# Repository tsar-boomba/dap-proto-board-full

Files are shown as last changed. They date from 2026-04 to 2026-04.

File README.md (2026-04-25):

# Bomb DAP Full Proto Board

The culmination of all of my learning during the Spring '26 semester. All the way from making a simple dev board for the TAD5212 DAC, to making a RP2350 board, and now this. Everything combined on one 6-layer board.

# V1 Pinouts

- GPIO0 -> PSRAM_CS
- GPIO1 -> npm1300 GPIO0
- GPIO2 -> DISP_IO_ON (level-shifter enable)
- GPIO3 -> Display Backlight
- GPIO4 -> Display SCLK
- GPIO5 -> Display MOSI
- GPIO6 -> Display MISO
- GPIO7 -> Display DC & SDA
- GPIO8 -> Display CS & SCL
- GPIO(9-11) -> Broken out
- GPIO12 -> SD MISO
- GPIO13 -> SD CS
- GPIO14 -> SD SCLK
- GPIO15 -> SD MOSI
- GPIO16 -> npm1300 SDA
- GPIO17 -> npm1300 SCL
- GPIO18 -> SD ON (load switch & level-shifter enable)
- GPIO19 -> TAD GPIO1
- GPIO20 -> TAD SDA
- GPIO21 -> TAD SCL
- GPIO(22-26) -> Broken out
- GPIO27 -> TAD DIN
- GPIO28 -> TAD FSYNC
- GPIO29 -> TAD BCLK

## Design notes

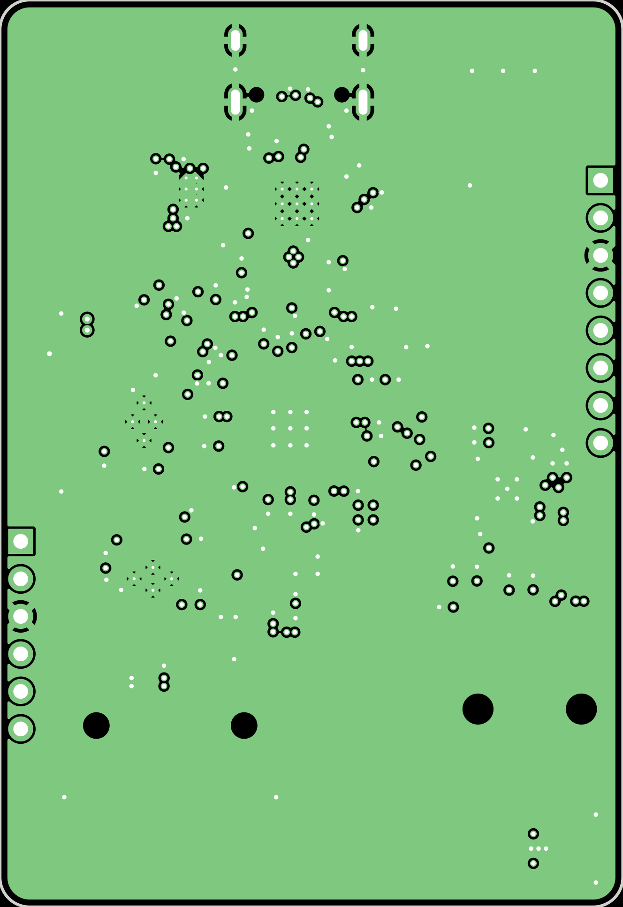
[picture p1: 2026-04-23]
In1.Cu.png

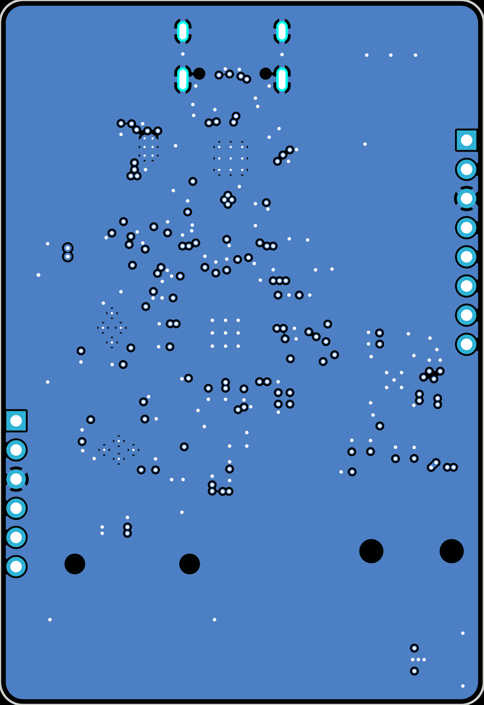
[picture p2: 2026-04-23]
B.png

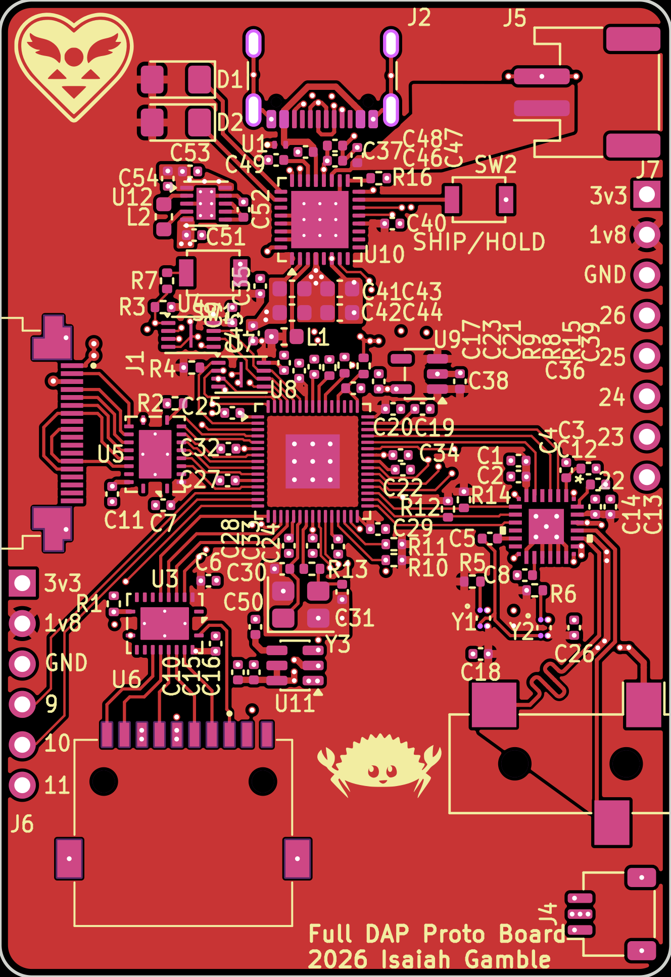
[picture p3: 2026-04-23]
F.png

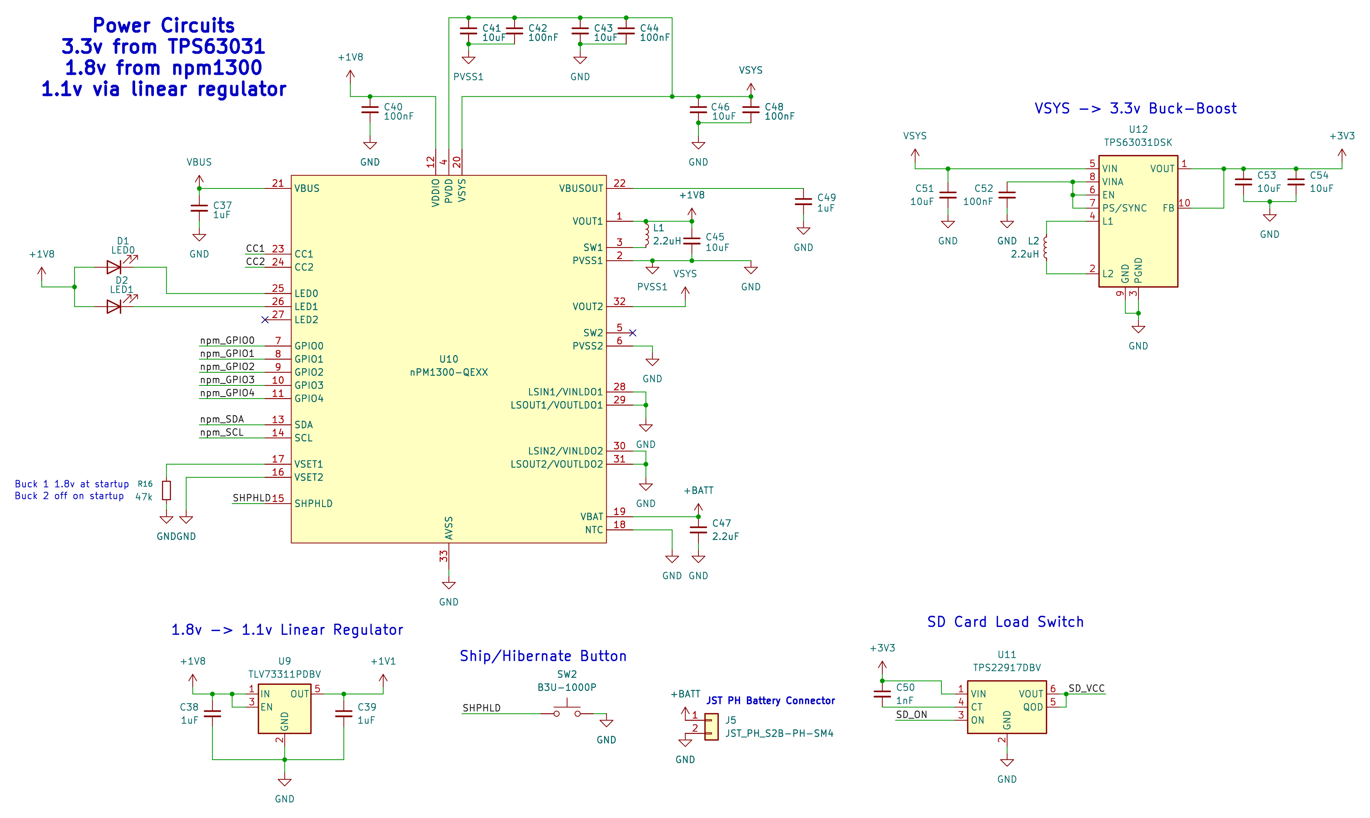
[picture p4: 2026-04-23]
SCH_2.png

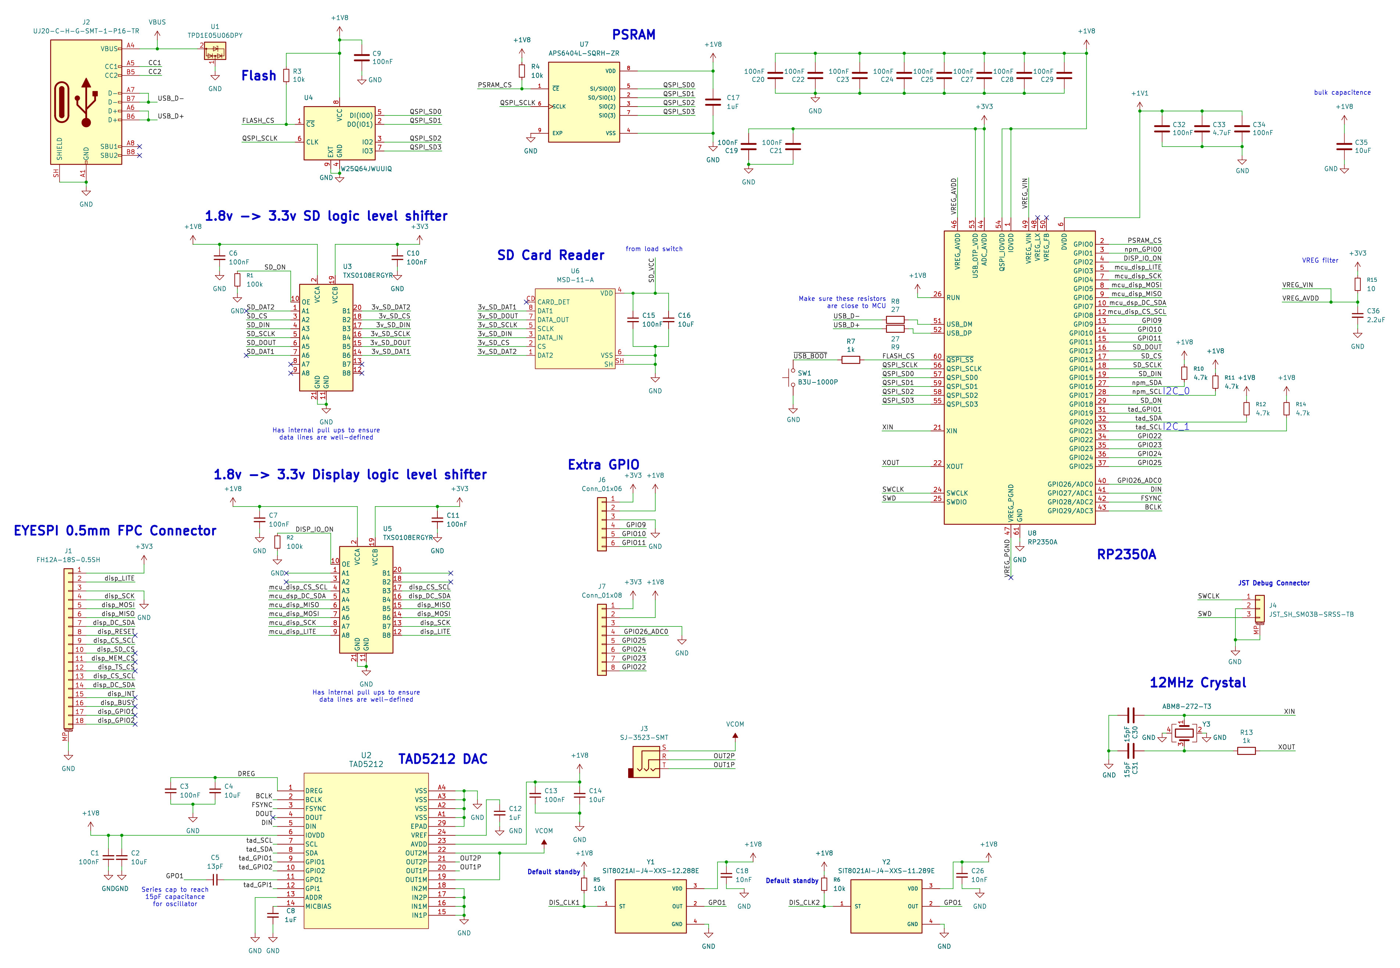
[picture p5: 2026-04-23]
SCH_1.png

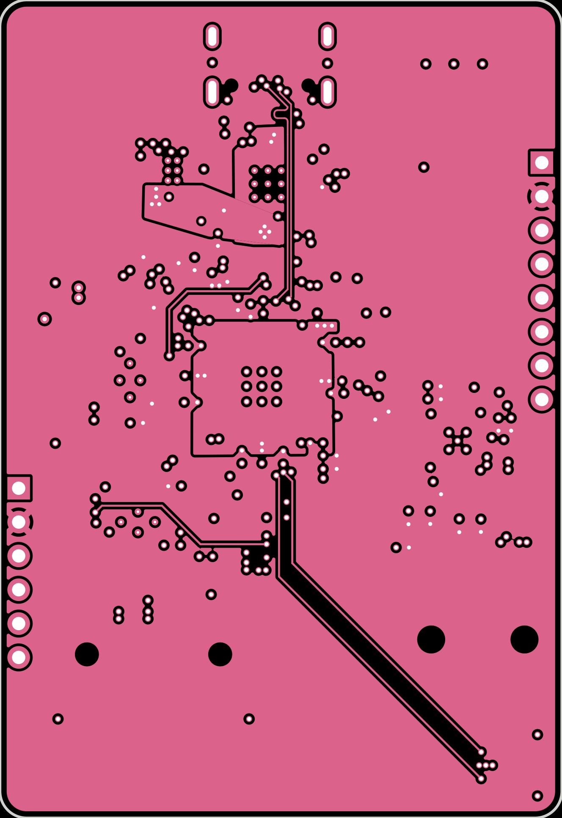
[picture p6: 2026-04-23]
In4.Cu.png

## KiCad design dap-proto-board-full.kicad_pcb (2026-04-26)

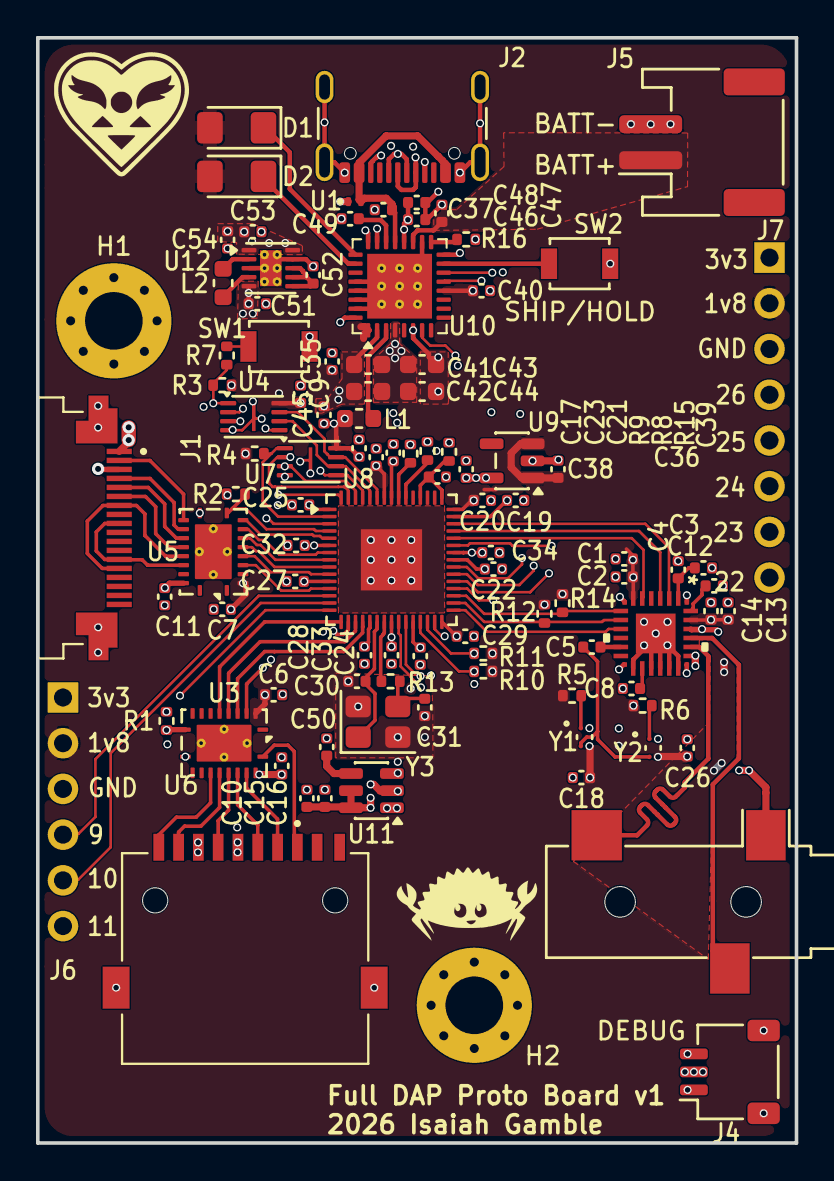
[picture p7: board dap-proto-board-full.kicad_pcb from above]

Board: 6 copper layers, 42.2 x 61.4 mm, 100 parts (0 on the bottom side), 89 nets.

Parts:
C1, C3, C6, C7, C9, C10, C11, C13, C15, C19, C20, C21, C22, C23, C24, C25, C27, C28, C29, C32, C34, C40, C48, C52: 100nF; C_0402_1005Metric
C2, C4, C14, C16, C35, C45, C46, C51, C53, C54: 10uF; C_0402_1005Metric
C5: 13pF; C_0402_1005Metric
C8, C12, C17, C37, C38, C39, C49: 1uF; C_0402_1005Metric
C18, C26: 10nF; C_0402_1005Metric
C30, C31: 15pF; C_0402_1005Metric
C33: 4.7uF; C_0402_1005Metric
C36, C47: 2.2uF; C_0402_1005Metric
C41, C43: 10uF; C_0603_1608Metric
C42, C44: 100nF; C_0603_1608Metric
C50: 1nF; C_0402_1005Metric
D1: LED0; LED_1206_3216Metric_Pad1.42x1.75mm_HandSolder
D2: LED1; LED_1206_3216Metric_Pad1.42x1.75mm_HandSolder
H1, H2: MountingHole_Pad; MountingHole_3.2mm_M3_Pad_Via
J1: SFV18R-1STE1HLF; AMPHENOL_SFV18R-1STE1HLF
J2: UJ20-C-H-G-SMT-1-P16-TR; USB_C_Receptacle_GCT_USB4105-xx-A_16P_TopMnt_Horizontal
J3: SJ-3523-SMT; Jack_3.5mm_CUI_SJ-3523-SMT_Horizontal
J4: JST_SH_SM03B-SRSS-TB; JST_SH_SM03B-SRSS-TB_1x03-1MP_P1.00mm_Horizontal
J5: JST_PH_S2B-PH-SM4; JST_PH_S2B-PH-SM4-TB_1x02-1MP_P2.00mm_Horizontal
J6: Conn_01x06; PinSocket_1x06_P2.54mm_Vertical
J7: Conn_01x08; PinSocket_1x08_P2.54mm_Vertical
L1, L2: 2.2uH; L_0603_1608Metric
R1, R2: 100k; R_0402_1005Metric
R3, R4, R5, R6: 10k; R_0402_1005Metric
R7, R13: 1k; R_0402_1005Metric
R8, R9: 27; R_0402_1005Metric
R10, R11, R12, R14: 4.7k; R_0402_1005Metric
R15: 10; R_0402_1005Metric
R16: 47k; R_0402_1005Metric
SW1, SW2: B3U-1000P; SW_SPST_B3U-1000P
U1: TPD1E05U06DPY; Texas_DPY0002A_0.6x1mm_P0.65mm
U2: TAD5212
U3, U5: TXS0108ERGYR; Texas_RGY_R-PVQFN-N20_EP2.05x3.05mm_ThermalVias
U4: W25Q64JWUUIQ; Winbond_USON-8-1EP_3x2mm_P0.5mm_EP0.2x1.6mm
U6: MSD-11-A; CUI_MSD-11-A
U7: APS6404L-SQRH-ZR; Winbond_USON-8-1EP_3x2mm_P0.5mm_EP0.2x1.6mm
U8: RP2350A; QFN-60-1EP_7x7mm_P0.4mm_EP3.4x3.4mm
U9: TLV73311PDBV; SOT-23-5
U10: nPM1300-QEXX; QFN-32-1EP_5x5mm_P0.5mm_EP3.6x3.6mm_ThermalVias
U11: TPS22917DBV; SOT-23-6
U12: TPS63031DSK; WSON-10-1EP_2.5x2.5mm_P0.5mm_EP1.2x2mm_ThermalVias
Y1: SIT8021AI-J4-XXS-12.288E; OSC_SIT8021AI-J4-XXS-24.000000E
Y2: SIT8021AI-J4-XXS-11.289E; OSC_SIT8021AI-J4-XXS-24.000000E
Y3: ABM8-272-T3; Crystal_SMD_3225-4Pin_3.2x2.5mm

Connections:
+1V1: C32.1, C33.1, C34.1, C39.1, U8.6 (DVDD), U8.23 (DVDD), U8.39 (DVDD), U9.5 (OUT)
+1V8: C1.2, C2.1, C6.1, C7.1, C9.1, C13.2, C14.2, C17.1, C18.1, C20.2, C22.2, C23.2, C24.2, C25.2, C26.1, C27.2, C28.2, C29.2, C35.1, C38.1, C40.1, C45.1, D1.2 (A), D2.2 (A), J6.2, J7.2, L1.1, R3.1, R4.1, R5.1, R6.1, R10.1, R11.1, R12.1, R14.1, U2.6 (IOVDD), U2.23 (AVDD), U3.2 (VCCA), U4.8 (VCC), U5.2 (VCCA), U7.8 (VDD), U8.1 (IOVDD), U8.11 (IOVDD), U8.20 (IOVDD), U8.26 (RUN), U8.30 (IOVDD), U8.38 (IOVDD), U8.45 (IOVDD), U8.54 (QSPI_IOVDD), U9.1 (IN), U9.3 (EN), U10.1 (VOUT1), U10.12 (VDDIO), Y1.3 (VDD), Y2.3 (VDD)
+3V3: C10.1, C11.1, C19.2, C21.2, C50.1, C53.1, C54.1, J1.1, J6.1, J7.1, R15.1, U3.19 (VCCB), U5.19 (VCCB), U8.44 (ADC_AVDD), U8.53 (USB_OTP_VDD), U11.1 (VIN), U12.1 (VOUT), U12.10 (FB)
+BATT: C47.1, J5.1, U10.19 (VBAT)
/3v_SD_CS: U3.18 (B2), U6.2 (CS)
/3v_SD_DAT1: U3.14 (B6), U6.8 (DAT1)
/3v_SD_DAT2: U3.20 (B1), U6.1 (DAT2)
/3v_SD_DIN: U3.17 (B3), U6.3 (DATA_IN)
/3v_SD_DOUT: U3.15 (B5), U6.7 (DATA_OUT)
/3v_SD_SCLK: U3.16 (B4), U6.5 (SCLK)
/BCLK: U2.2 (BCLK), U8.43 (GPIO29/ADC3)
/CC1: J2.A5 (CC1), U10.23 (CC1)
/CC2: J2.B5 (CC2), U10.24 (CC2)
/DIN: U2.5 (DIN), U8.41 (GPIO27/ADC1)
/DISP_IO_ON: R2.1, U5.10 (OE), U8.4 (GPIO2)
/DIS_CLK1: R5.2, Y1.1 (ST)
/DIS_CLK2: R6.2, Y2.1 (ST)
/DREG: C3.2, C4.1, U2.1 (DREG)
/FLASH_CS: R3.2, R7.1, U4.1 (~CS), U8.60 (~QSPI_SS)
/FSYNC: U2.3 (FSYNC), U8.42 (GPIO28/ADC2)
/GPIO9: J6.4, U8.13 (GPIO9)
/GPIO10: J6.5, U8.14 (GPIO10)
/GPIO11: J6.6, U8.15 (GPIO11)
/GPIO22: J7.8, U8.34 (GPIO22)
/GPIO23: J7.7, U8.35 (GPIO23)
/GPIO24: J7.6, U8.36 (GPIO24)
/GPIO25: J7.5, U8.37 (GPIO25)
/GPIO26_ADC0: J7.4, U8.40 (GPIO26/ADC0)
/GPO1: C5.1, Y1.2 (OUT), Y2.2 (OUT)
/OUT1P: J3.T, U2.20 (OUT1P)
/OUT2P: J3.R, U2.21 (OUT2P)
/PSRAM_CS: R4.2, U7.1 (~CE), U8.2 (GPIO0)
/QSPI_SCLK: U4.6 (CLK), U7.6 (SCLK), U8.56 (QSPI_SCLK)
/QSPI_SD0: U4.5 (DI(IO0)), U7.5 (SI/SIO(0)), U8.57 (QSPI_SD0)
/QSPI_SD1: U4.2 (DO(IO1)), U7.2 (SO/SIO(1)), U8.59 (QSPI_SD1)
/QSPI_SD2: U4.3 (IO2), U7.3 (SIO(2)), U8.58 (QSPI_SD2)
/QSPI_SD3: U4.7 (IO3), U7.7 (SIO(3)), U8.55 (QSPI_SD3)
/SD_CS: U3.3 (A2), U8.17 (GPIO13)
/SD_DIN: U3.4 (A3), U8.19 (GPIO15)
/SD_DOUT: U3.6 (A5), U8.16 (GPIO12)
/SD_ON: R1.1, U3.10 (OE), U8.29 (GPIO18), U11.3 (ON)
/SD_SCLK: U3.5 (A4), U8.18 (GPIO14)
/SD_VCC: C15.1, C16.1, U6.4 (VDD), U11.5 (QOD), U11.6 (VOUT)
/SHPHLD: SW2.1, U10.15 (SHPHLD)
/SWCLK: J4.1, U8.24 (SWCLK)
/SWD: J4.3, U8.25 (SWDIO)
/USB_D+: J2.A6 (D+), J2.B6 (D+), R9.1
/USB_D-: J2.A7 (D-), J2.B7 (D-), R8.1
/VREG_AVDD: C36.1, R15.2, U8.46 (VREG_AVDD), U8.49 (VREG_VIN)
/XIN: C30.1, U8.21 (XIN), Y3.1
/XOUT: R13.1, U8.22 (XOUT)
/disp_CS_SCL: J1.9, J1.13, U5.17 (B3)
/disp_DC_SDA: J1.7, J1.14, U5.16 (B4)
/disp_LITE: J1.2, U5.12 (B8)
/disp_MISO: J1.6, U5.15 (B5)
/disp_MOSI: J1.5, U5.14 (B6)
/disp_SCK: J1.4, U5.13 (B7)
/mcu_disp_CS_SCL: U5.4 (A3), U8.12 (GPIO8)
/mcu_disp_LITE: U5.9 (A8), U8.5 (GPIO3)
/mcu_disp_MISO: U5.6 (A5), U8.9 (GPIO6)
/mcu_disp_MOSI: U5.7 (A6), U8.8 (GPIO5)
/mcu_disp_SCK: U5.8 (A7), U8.7 (GPIO4)
/mcu_dsp_DC_SDA: U5.5 (A4), U8.10 (GPIO7)
/npm_GPIO0: U8.3 (GPIO1), U10.7 (GPIO0)
/npm_SCL: R11.2, U8.28 (GPIO17), U10.14 (SCL)
/npm_SDA: R10.2, U8.27 (GPIO16), U10.13 (SDA)
/tad_GPIO1: U2.9 (GPIO1), U8.31 (GPIO19)
/tad_SCL: R14.2, U2.7 (SCL), U8.33 (GPIO21)
/tad_SDA: R12.2, U2.8 (SDA), U8.32 (GPIO20)
/~USB_BOOT: R7.2, SW1.2
GND: C1.1, C2.2, C3.1, C4.2, C6.2, C7.2, C8.2, C9.2, C10.2, C11.2, C12.2, C13.1, C14.1, C15.2, C16.2, C17.2, C18.2, C19.1, C20.1, C21.1, C22.1, C23.1, C24.1, C25.1, C26.2, C27.1, C28.1, C29.1, C30.2, C31.2, C32.2, C33.2, C34.2, C35.2, C36.2, C37.2, C38.2, C39.2, C40.2, C41.2, C42.2, C43.2, C44.2, C45.2, C46.2, C47.2, C48.2, C49.2, C51.2, C52.2, C53.2, C54.2, H1.1 (1_1), H2.1 (1_1), J1.3, J1.MP (MountPin), J2.A1 (GND), J2.A12 (GND), J2.B1 (GND), J2.B12 (GND), J2.SH (SHIELD), J4.2, J4.MP (MountPin), J5.2, J6.3, J7.3, R1.2, R2.2, R16.2, SW1.1, SW2.2, U1.1 (I/O), U2.13 (ADDR), U2.15 (IN1P), U2.16 (IN1M), U2.17 (IN2P), U2.18 (IN2M), U2.29 (EPAD), U2.A1 (VSS), U2.A2 (VSS), U2.A3 (VSS), U2.A4 (VSS), U3.11 (GND), U3.21 (GND), U4.4 (GND), U4.9 (EXT), U5.11 (GND), U5.21 (GND), U6.6 (VSS), U6.SH, U7.4 (VSS), U7.9 (EXP), U8.61 (GND), U9.2 (GND), U10.2 (PVSS1), U10.6 (PVSS2), U10.16 (VSET2), U10.18 (NTC), U10.28 (LSIN1/VINLDO1), U10.29 (LSOUT1/VOUTLDO1), U10.30 (LSIN2/VINLDO2), U10.31 (LSOUT2/VOUTLDO2), U10.33 (AVSS), U11.2 (GND), U12.3 (PGND), U12.9 (GND), U12.11 (PGND), Y1.4 (GND), Y2.4 (GND), Y3.2, Y3.4
unnamed: C31.1, R13.2, Y3.3
unnamed: D1.1 (K), U10.25 (LED0)
unnamed: D2.1 (K), U10.26 (LED1)
unnamed: C5.2, U2.11 (GPO1)
unnamed: C8.1, U2.14 (MICBIAS)
unnamed: C12.1, U2.24 (VREF)
unnamed: R8.2, U8.51 (USB_DM)
unnamed: R9.2, U8.52 (USB_DP)
unnamed: L1.2, U10.3 (SW1)
unnamed: C49.1, U10.22 (VBUSOUT)
unnamed: R16.1, U10.17 (VSET1)
unnamed: C50.2, U11.4 (CT)
unnamed: C52.1, U12.6 (EN), U12.7 (PS/SYNC), U12.8 (VINA)
unnamed: L2.1, U12.4 (L1)
unnamed: L2.2, U12.2 (L2)
VBUS: C37.1, J2.A4 (VBUS), J2.A9 (VBUS), J2.B4 (VBUS), J2.B9 (VBUS), U1.2 (GND), U10.21 (VBUS)
VCOM: J3.S, U2.19 (OUT1M), U2.22 (OUT2M)
VSYS: C41.1, C42.1, C43.1, C44.1, C46.1, C48.1, C51.1, U10.4 (PVDD), U10.20 (VSYS), U10.32 (VOUT2), U12.5 (VIN)

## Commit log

2026-04-23 kinda v1
    [dap-proto-board-full-B_Cu.gbl, dap-proto-board-full-B_Mask.gbs, dap-proto-board-full-B_Paste.gbp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]
2026-04-25 make ground plane solid + docs
    [dap-proto-board-full.kicad_pcb]
2026-04-26 decrease min width of ground fill around crystal
    [dap-proto-board-full.kicad_pcb]
